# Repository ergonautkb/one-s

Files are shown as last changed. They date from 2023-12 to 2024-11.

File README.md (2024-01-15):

# Ergonaut One S

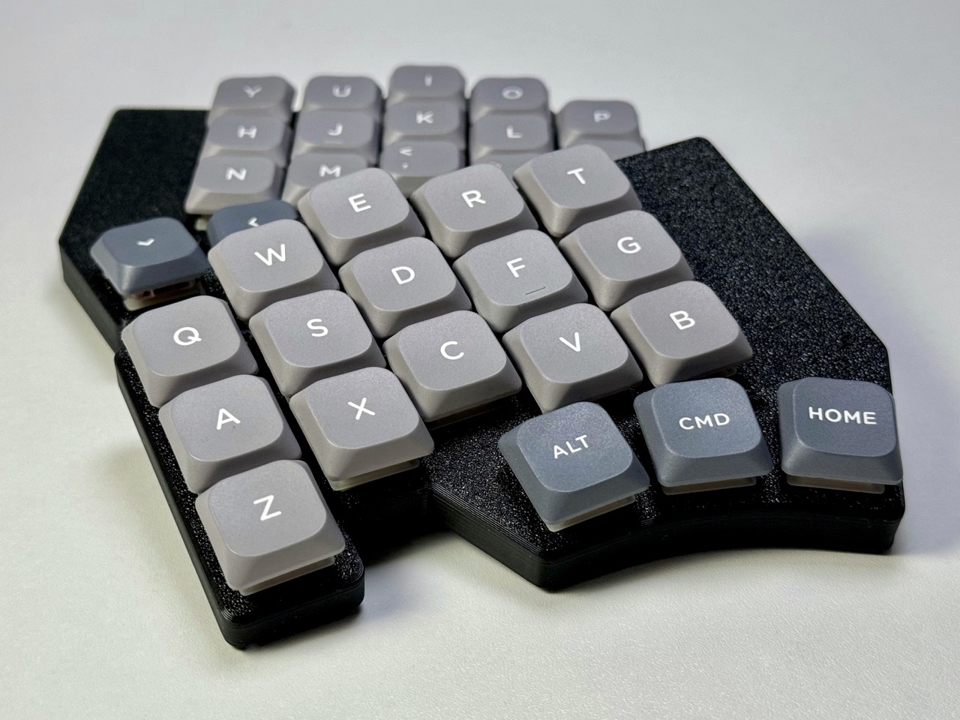
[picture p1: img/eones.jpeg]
Ergonaut One S Header Image

*Ergonaut One S in Modern Case*

Ergonaut One S is an open-source ergonomic wireless split mechanical keyboard designed by Ergonaut Keyboards.

Inspiration for the keyboard was taken from these projects:

- [Ergonaut One](https://ergonautkb.com/docs/keyboards/ergonaut-one/intro/) by [Ergonaut Keyboards](https://ergonautkb.com/)
- [Chocofi](https://github.com/pashutk/chocofi/) by [pashutk](https://github.com/pashutk/)

## Idea

We wanted to create a pretty affordable, nice looking, and, most importantly, very DIY-friendly ergonomic wireless split keyboard with Gateron Low Profile switches.

## Features

* Low-profile, which will reduce strain on your beautiful hands;
* Split. You can put the keyboard where it'll be comfortable exactly for you;
* Pretty long battery life. 250mAh battery gives up to a month of usage without charging;
* Wide availability and range of [compatible keycaps](https://ergonautkb.com/docs/switches/gateron-low-profile#keycaps-compatibility);
* Budget-friendly, because:
  * It uses relatively cheap and widely available [Seeed Studio XIAO nRF52840](https://wiki.seeedstudio.com/XIAO_BLE/) as MCU;
  * It uses one PCB design for both halves of the keyboard;
  * Everything except PCB's, components and hardware (screws, nuts) can be 3D printed.
* Beginner-friendly, because:
  * PCB is easy to solder;
  * Cases are easy to print.
* Wireless by design - no unnecessary wires, no unused connectors on the board;
* Free in terms of hardware design. It's licensed under permissive [CERN-OHL-P v2](https://ohwr.org/cern_ohl_p_v2.pdf) license, which means:
  * you are free to manufacture it yourself;
  * you are free to sell your manufactured hardware for profit.

## Build Guide

BOM and Build Guide can be found in [Ergonaut Keyboards Documentation Portal](https://ergonautkb.com/docs/keyboards/ergonaut-one-s/intro).

## Firmware

Firmware can be found in [one-zmk-config](https://github.com/ergonautkb/one-s-zmk-config) repository.

## Gerbers

| Front | Back |
| --- | --- |
| front | back |

* [JLCPCB](../../releases/latest/download/pcb-JLCPCB_gerbers.zip)
* [PCBWay](../../releases/latest/download/pcb-PCBWay_gerbers.zip)

## Contacts

* Documentation portal: https://ergonautkb.com
* Telegram: https://ergonautkb.t.me
* Telegram (ru): https://ergonautkb_ru.t.me

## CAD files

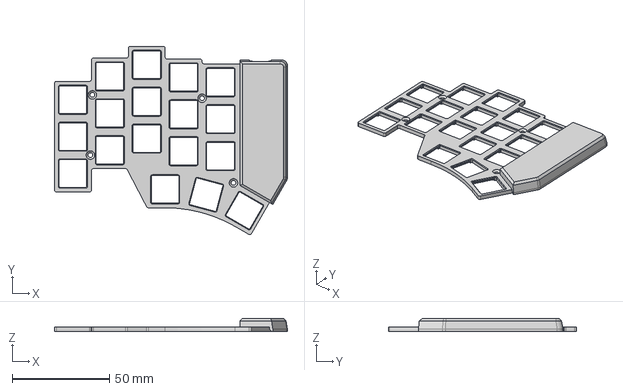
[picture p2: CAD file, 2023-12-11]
cases/3d/classic/step/top.step
120.0 x 97.0 x 6.70 mm

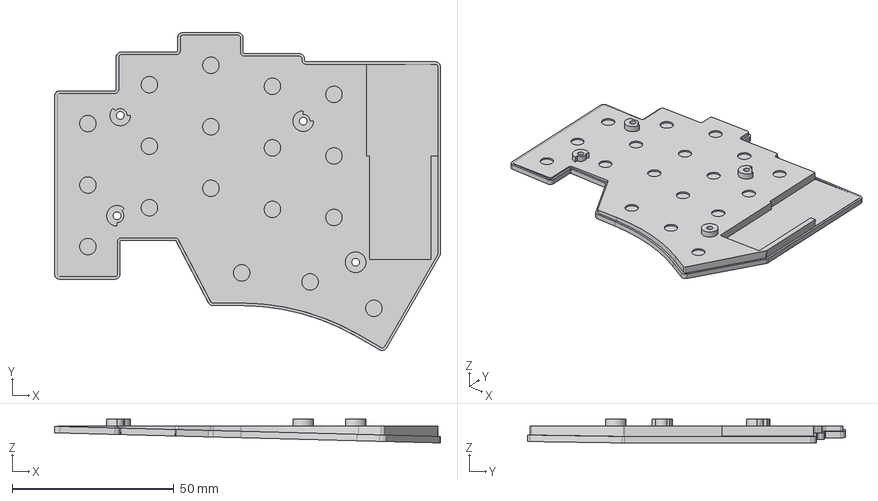
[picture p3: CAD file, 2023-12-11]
cases/3d/modern/step/bottom.step
119.2 x 98.2 x 7.38 mm

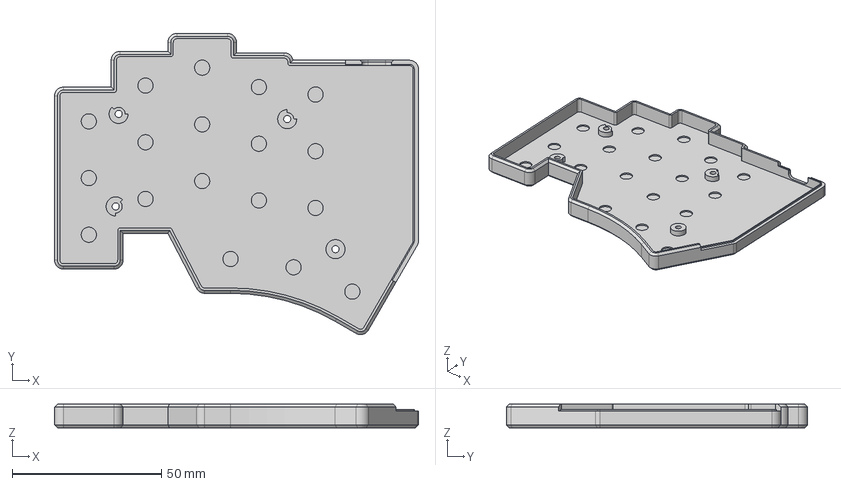
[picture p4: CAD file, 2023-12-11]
cases/3d/classic/step/bottom.step
122.0 x 101.0 x 8.00 mm

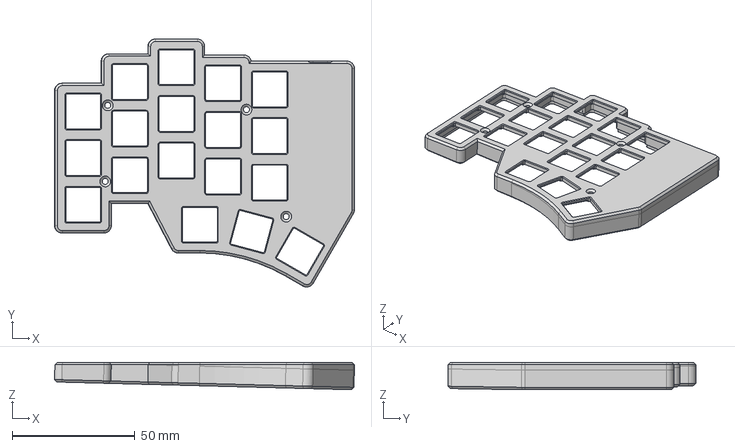
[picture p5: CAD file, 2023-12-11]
cases/3d/modern/step/top.step
122.2 x 101.0 x 11.2 mm

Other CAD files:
cases/3d/classic/stl/bottom.stl
cases/3d/classic/stl/top.stl
cases/3d/modern/stl/bottom.stl
cases/3d/modern/stl/top.stl

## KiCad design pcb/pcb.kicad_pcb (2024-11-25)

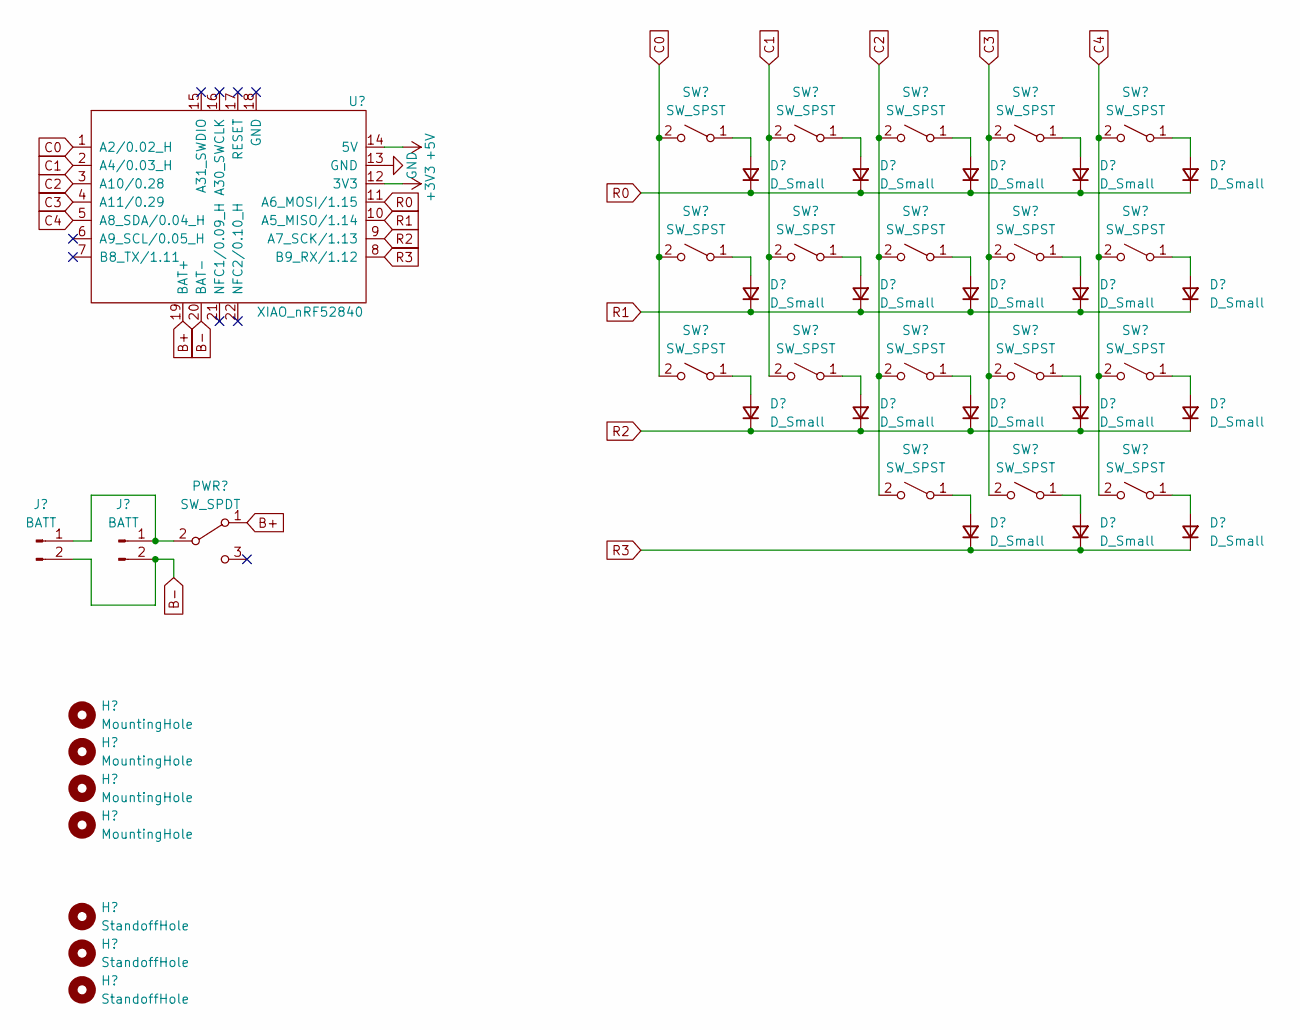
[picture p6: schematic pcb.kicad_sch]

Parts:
D1, D2, D3, D4, D5, D6, D7, D8, D9, D10, D11, D12, D13, D14, D15, D16, D17, D18: D_Small; Diode_TH_SMD_DUAL
H1, H2, H3, H4: MountingHole; Hole_4.2mm
H5, H6, H7: StandoffHole; Hole_2.2mm
J1: BATT; JST_SH_Battery_DUAL
J2: BATT; Battery
PWR1: SW_SPDT; MSK-12C02_DUAL
SW1, SW2, SW3, SW4, SW5, SW6, SW7, SW8, SW9, SW10, SW11, SW12, SW13, SW14, SW15, SW16, SW17, SW18: SW_SPST; KS-27_KS-33_Hotswap_1U_DUAL
U1: XIAO_nRF52840; XIAO_nRF52840_DUAL

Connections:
+3V3: U1.12 (3V3)
+5V: U1.14 (5V)
B+: PWR1.1 (A), U1.19 (BAT+)
B-: J1.2, J2.2, U1.20 (BAT-)
C0: SW1.2 (B), SW6.2 (B), SW11.2 (B), U1.1 (A2/0.02_H)
C1: SW2.2 (B), SW7.2 (B), SW12.2 (B), U1.2 (A4/0.03_H)
C2: SW3.2 (B), SW8.2 (B), SW13.2 (B), SW16.2 (B), U1.3 (A10/0.28)
C3: SW4.2 (B), SW9.2 (B), SW14.2 (B), SW17.2 (B), U1.4 (A11/0.29)
C4: SW5.2 (B), SW10.2 (B), SW15.2 (B), SW18.2 (B), U1.5 (A8_SDA/0.04_H)
GND: U1.13 (GND)
unnamed: D1.2 (A), SW1.1 (A)
unnamed: D2.2 (A), SW2.1 (A)
unnamed: D3.2 (A), SW3.1 (A)
unnamed: D4.2 (A), SW4.1 (A)
unnamed: D5.2 (A), SW5.1 (A)
unnamed: D6.2 (A), SW6.1 (A)
unnamed: D7.2 (A), SW7.1 (A)
unnamed: D8.2 (A), SW8.1 (A)
unnamed: D9.2 (A), SW9.1 (A)
unnamed: D10.2 (A), SW10.1 (A)
unnamed: D11.2 (A), SW11.1 (A)
unnamed: D12.2 (A), SW12.1 (A)
unnamed: D13.2 (A), SW13.1 (A)
unnamed: D14.2 (A), SW14.1 (A)
unnamed: D15.2 (A), SW15.1 (A)
unnamed: D16.2 (A), SW16.1 (A)
unnamed: D17.2 (A), SW17.1 (A)
unnamed: D18.2 (A), SW18.1 (A)
unnamed: J1.1, J2.1, PWR1.2 (B)
R0: D1.1 (K), D2.1 (K), D3.1 (K), D4.1 (K), D5.1 (K), U1.11 (A6_MOSI/1.15)
R1: D6.1 (K), D7.1 (K), D8.1 (K), D9.1 (K), D10.1 (K), U1.10 (A5_MISO/1.14)
R2: D11.1 (K), D12.1 (K), D13.1 (K), D14.1 (K), D15.1 (K), U1.9 (A7_SCK/1.13)
R3: D16.1 (K), D17.1 (K), D18.1 (K), U1.8 (B9_RX/1.12)

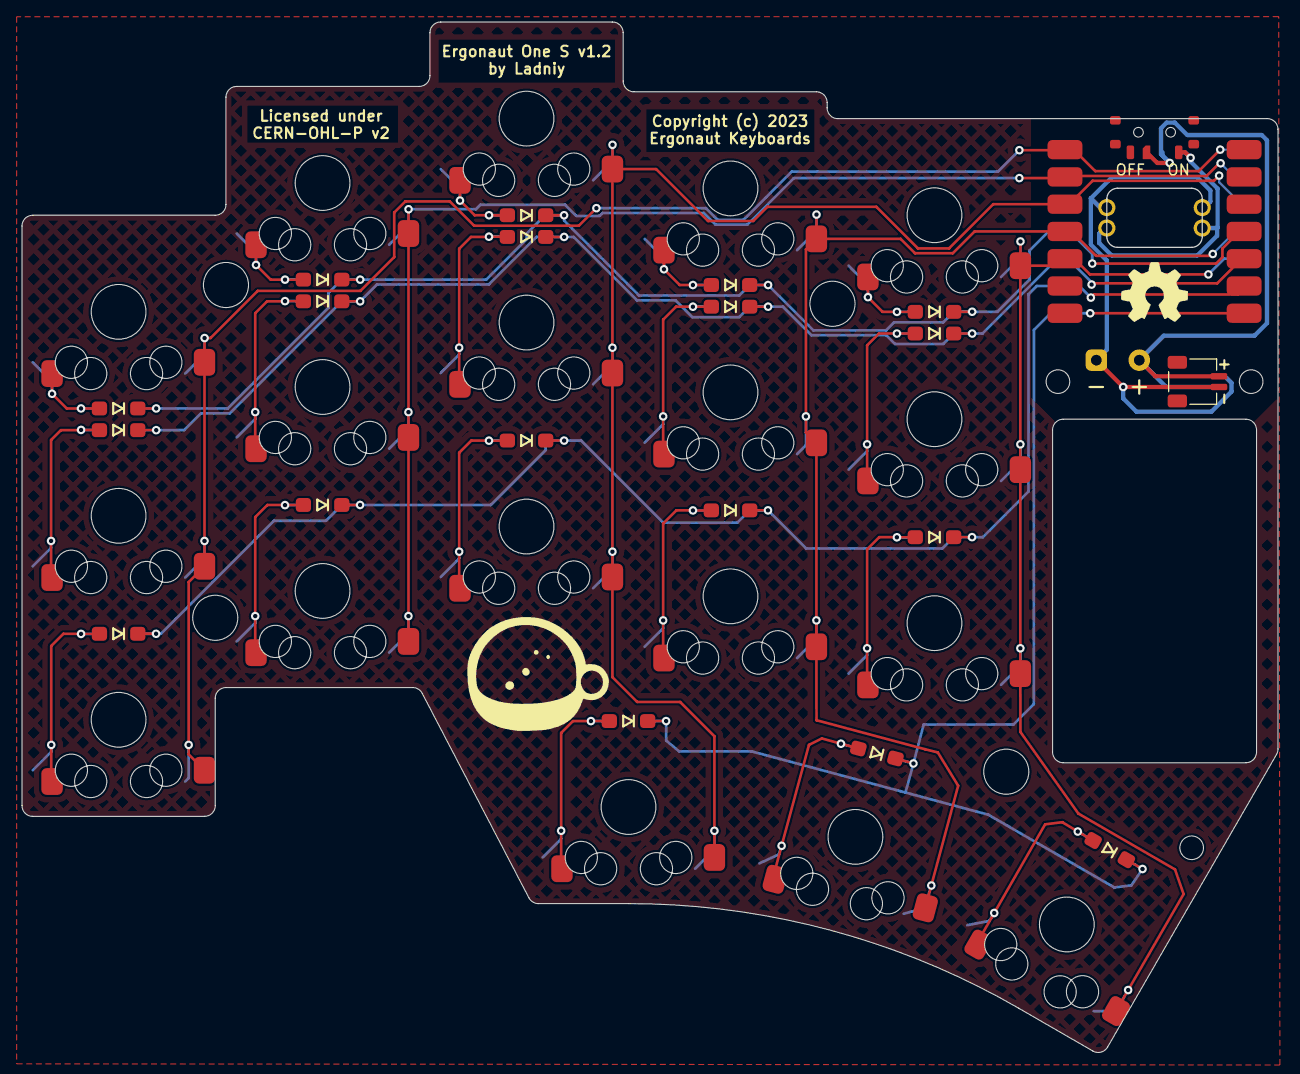
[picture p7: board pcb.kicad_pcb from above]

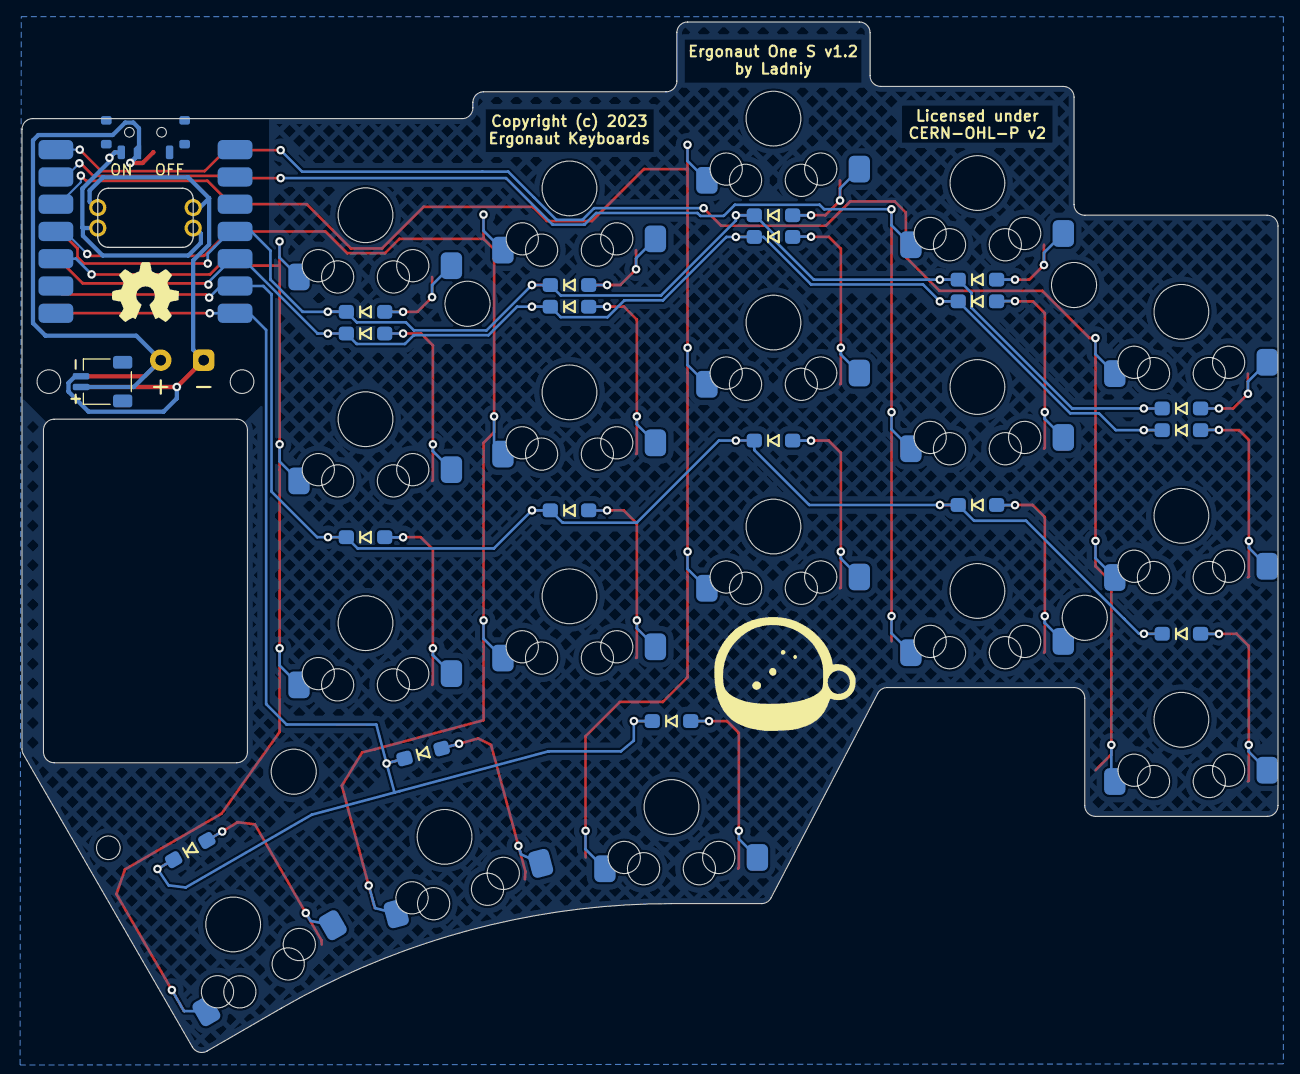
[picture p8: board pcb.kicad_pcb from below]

Board: 2 copper layers, 117.0 x 96.0 mm, 47 parts (19 on the bottom side), 30 nets.

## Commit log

2023-07-31 feat: add basic drawing
    [scuffy-basic.dxf]
2023-07-31 feat: add libs for kicad
2023-07-31 feat: pcb scheme is ready
    [pcb.kicad_sch]
2023-07-31 fix: symbol references
    [pcb.kicad_sch]
2023-08-01 feat: place all components on pcb
    [pcb.kicad_pcb]
2023-08-01 fix: silkscreen
    [pcb.kicad_pcb]
2023-08-09 fix: diode placement
    [pcb.kicad_pcb]
2023-09-03 feat: everything ready (no way)
    [pcb.kicad_pcb]
2023-12-07 feat: a lot of things, more in future pr
    [pcb.kicad_pcb]
2023-12-07 feat: add keepout zone around mcu
    [pcb.kicad_pcb]
2023-12-11 feat: change fillets radius on battery cutout and move keepout zones a bit
    [pcb.kicad_pcb]
2023-12-11 add ci and 3d files
    [bottom.step, bottom.stl, pcb.kicad_pcb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]
2024-02-29 Round and enlarge xiao pads, add cutout under controller (#3)
    [pcb.kicad_pcb]
2024-11-24 V1.2: fix missing traces on right half
    [pcb.kicad_pcb]

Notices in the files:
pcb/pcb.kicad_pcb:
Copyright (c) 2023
